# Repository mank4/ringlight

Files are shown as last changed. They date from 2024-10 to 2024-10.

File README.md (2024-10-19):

# Ringlight

ringlight is a LED ringlight for the Wild M3B stereo microscope. It it is mounted using the objective and does not stick out from the shape of the Wild M3B. ringlight requires 2 PCBs, one for the control and one aluminum core PCB (normal PCB should be also sufficient) for the LEDs. A spacer for mounting can be 3D printed.
The inner diameter of the LED PCB is chosen so that a photography polarization filter could be placed inside, but this is not tested. There are also mounting threads for a lens, intended to be 3D printed using clear resin with the option to mount a polarization filter foil onto the LED side. This is also not tested.

Feature:
- 24x Cree J Series 2835 high-CRI LEDs
- 10-step brightness control
- full circle, half circle and quarter circle modes with adjustable section size
- more configurations using SCPI pc-based control via USB

## RP2040 toolchain

Clone ringlight next to pico folder containing pico-examples, pico-sdk and picotool.

- Clone dependencies: `git submodule init` and `git submodule update`
- Create build folder in firmware and cd into. `cd fw && mkdir build && cd build`
- Then run `export PICO_SDK_PATH=../../../pico/pico-sdk` and `cmake ..`
- Then `make -j4`
- If compilation fails with USB descriptor length errors, do the following, cd into pico-sdk folder and `cd lib/tinyusb/` and then `git pull origin master`
- Then `../load.sh` with the RP2040 connected via USB. Press the button before pluggin in. (This is not needed when running the firmware. Make sure that picotool is build and you have set up the udev rules for the pico [udev rules](https://gist.github.com/alejoseb/c7a7b4c67f0cf665dadabb26a5a87597) and the ringlight:
```
/etc/udev/rules.d/99-ringlight.rules
SUBSYSTEMS=="usb", ACTION=="add", ATTRS{idVendor}=="16c0", ATTRS{idProduct}=="03e8",  MODE="0666", GROUP="usbtmc"
```

For details see the [Getting started](https://datasheets.raspberrypi.com/pico/getting-started-with-pico.pdf) guide.

## Resources

- Microcontroller
  - [RP2040](https://www.raspberrypi.com/documentation/microcontrollers/rp2040.html), [Pi pico](https://www.raspberrypi.com/products/raspberry-pi-pico/), RP2040 Minimal Kicad reference design
  - [SCPI specifications](https://www.ivifoundation.org/specifications/default.aspx), [SCPI-99 standard](https://www.ivifoundation.org/docs/scpi-99.pdf), [SCPI library](https://github.com/j123b567/scpi-parser)
  - [tinyusb for usbtmc](https://github.com/hathach/tinyusb), [example](https://github.com/markb139/pico_logic)

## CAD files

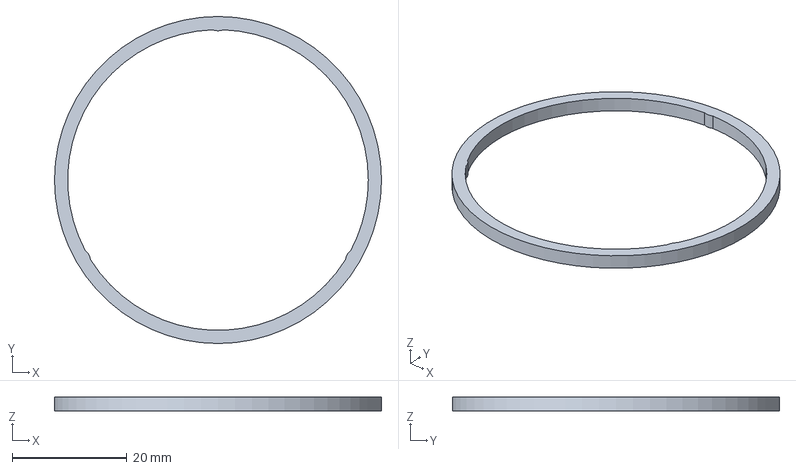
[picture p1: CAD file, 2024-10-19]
case/spacer1.FCStd
57.0 x 57.0 x 2.50 mm

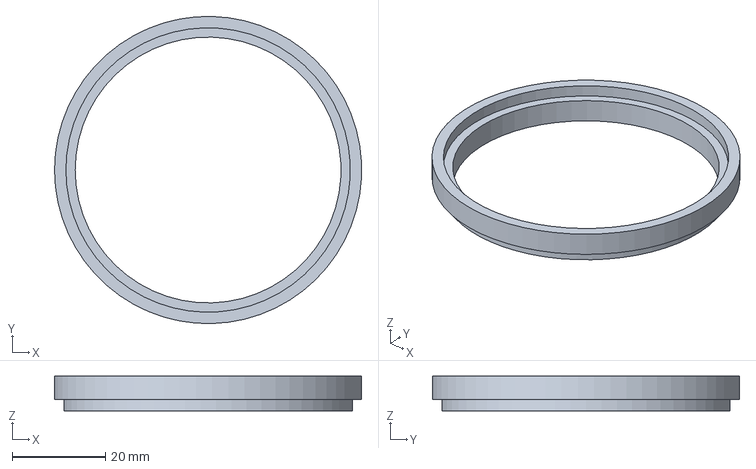
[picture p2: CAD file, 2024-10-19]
lens/filter.step
66.0 x 66.0 x 7.50 mm

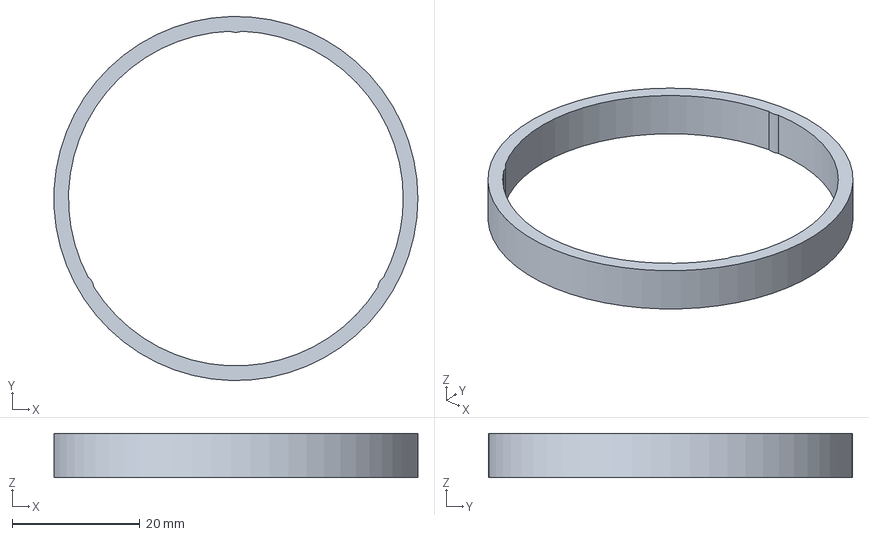
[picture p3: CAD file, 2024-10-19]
case/spacer2.FCStd
57.0 x 57.0 x 6.90 mm

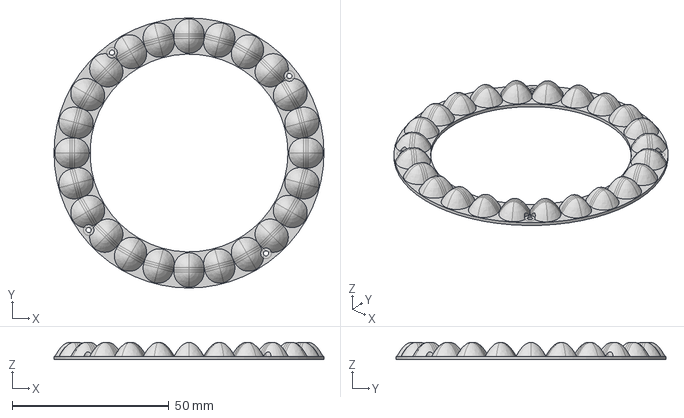
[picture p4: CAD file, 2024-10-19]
lens/lens.step
86.0 x 86.0 x 5.50 mm

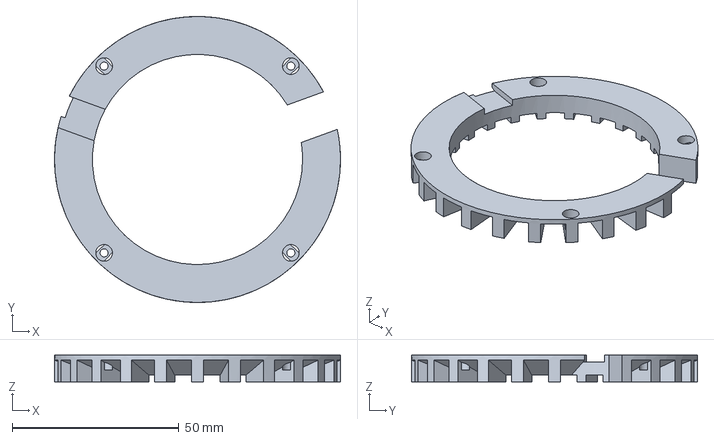
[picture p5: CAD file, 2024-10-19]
case/case.FCStd
85.7 x 85.7 x 8.00 mm

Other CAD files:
lens/lens.FCStd

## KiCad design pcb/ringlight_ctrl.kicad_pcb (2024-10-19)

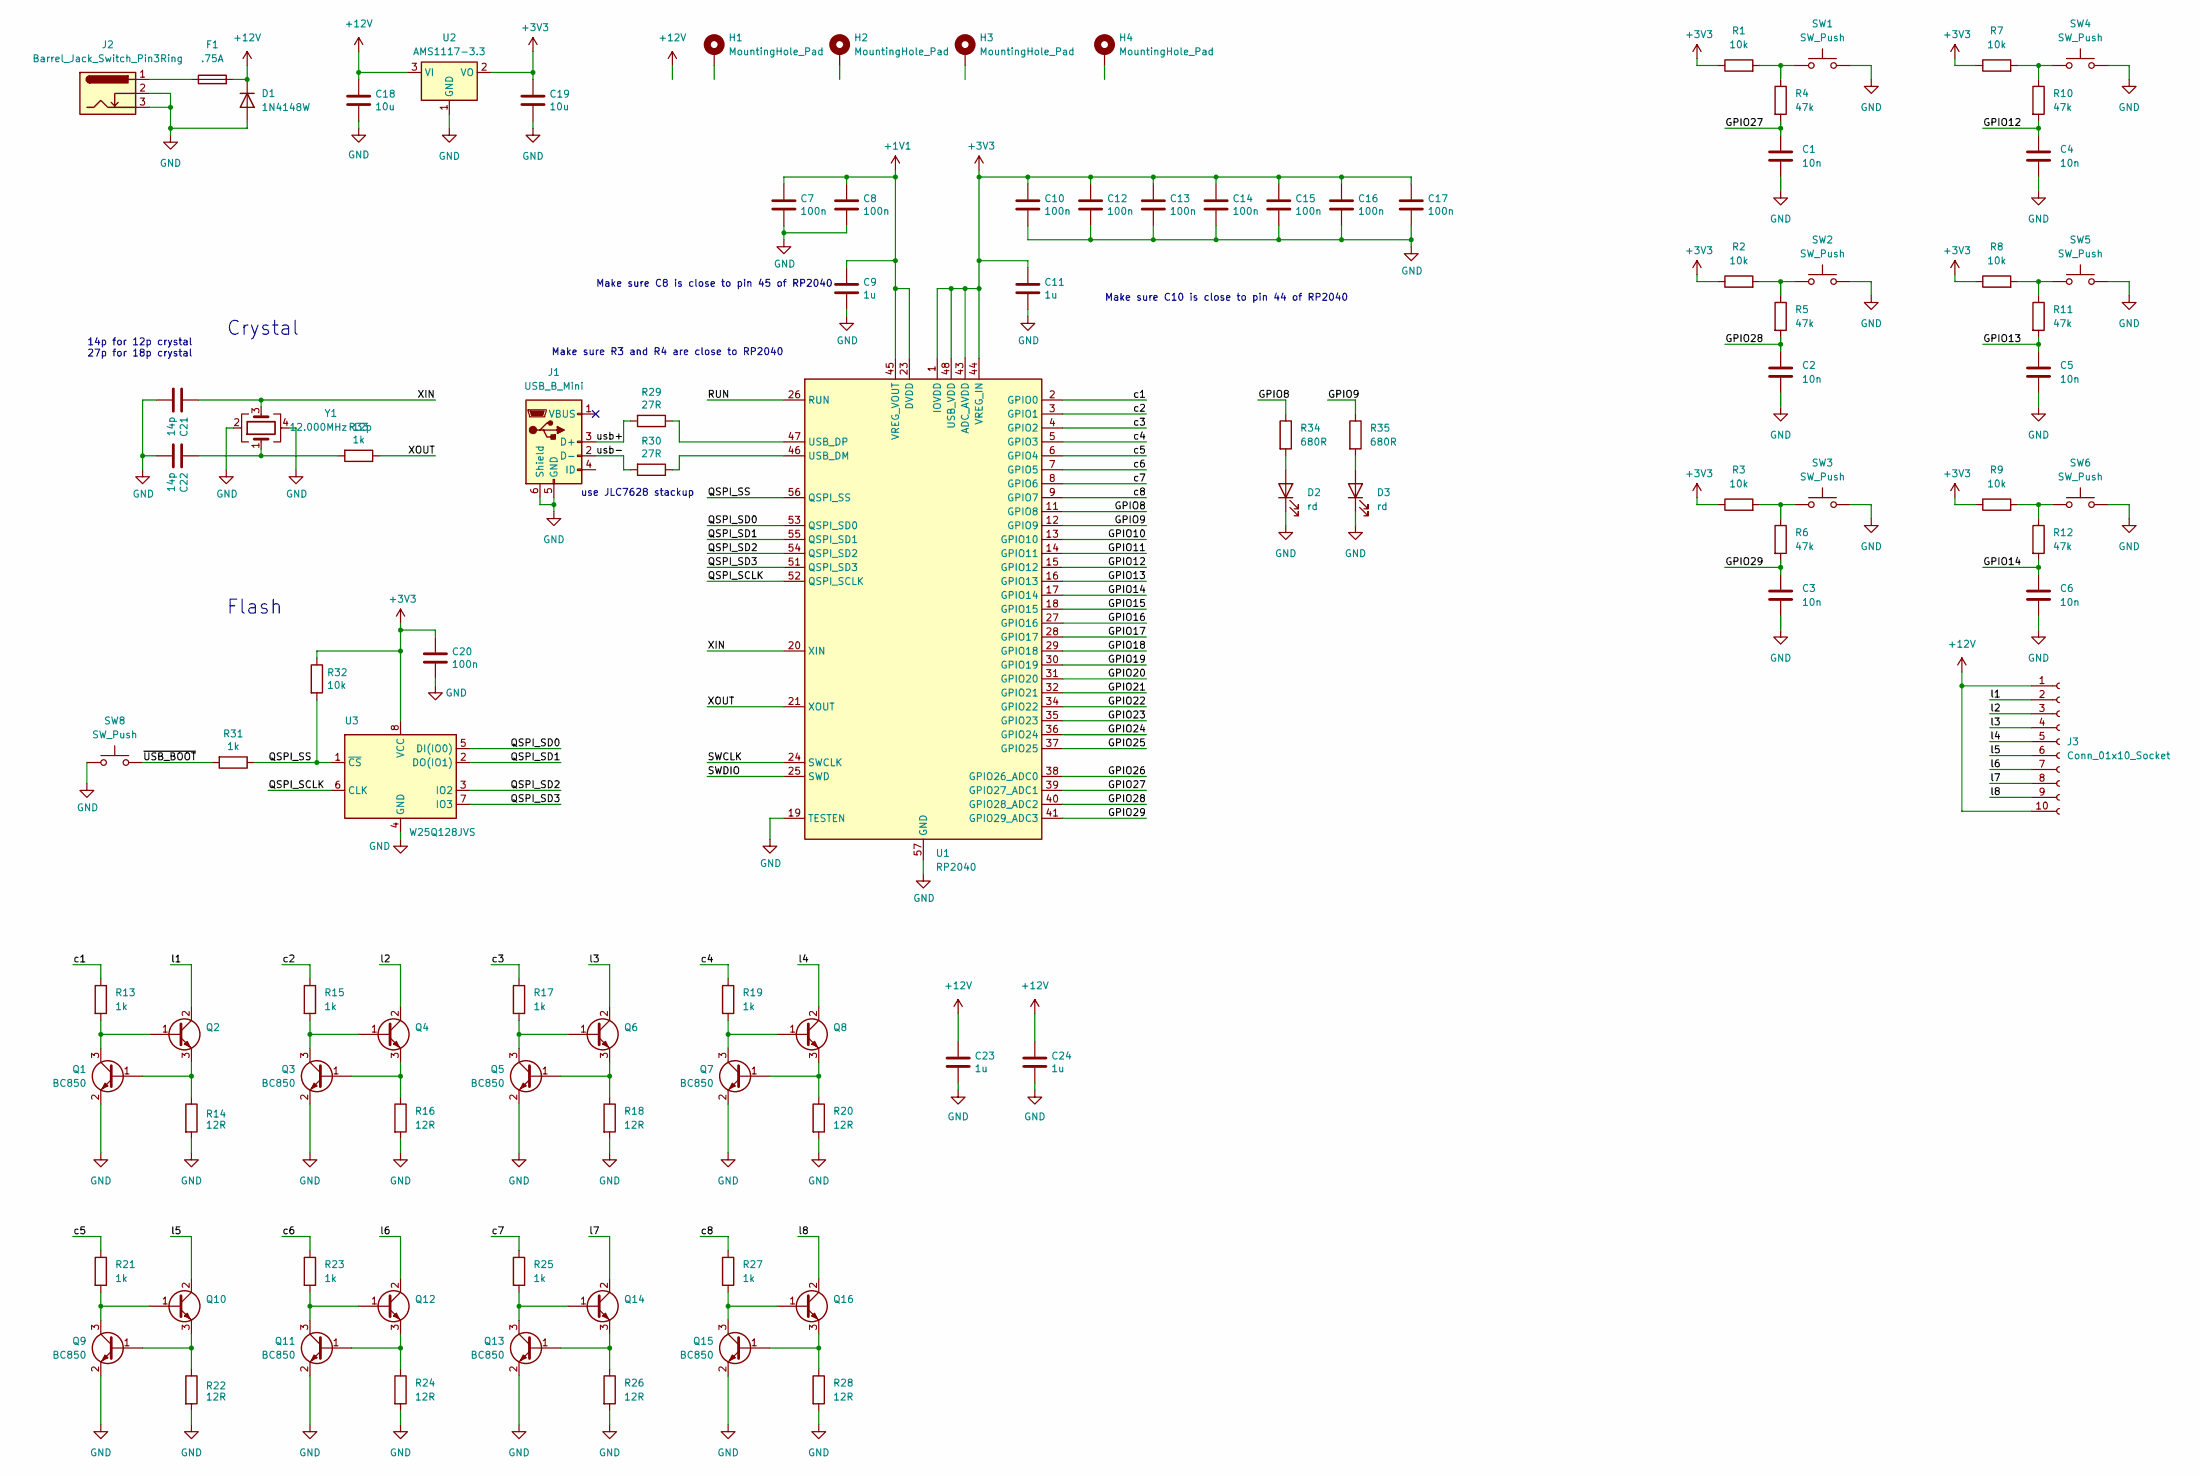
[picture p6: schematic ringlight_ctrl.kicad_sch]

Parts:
C1, C2, C3, C4, C5, C6: 10n; C_0805_2012Metric
C7, C8, C10, C12, C13, C14, C15, C16, C17, C20: 100n; C_0805_2012Metric
C9, C11, C23, C24: 1u; C_0805_2012Metric
C18, C19: 10u; C_0805_2012Metric
C21, C22: 14p; C_0805_2012Metric
D1: 1N4148W; D_SOD-123; Digikey 4878-1N4148WCT-ND
D2, D3: rd; LED_Kingbright_APA1606_1.6x0.6mm_Horizontal; Digikey 754-1054-1-ND
F1: .75A; Fuse_1206_3216Metric; Digikey 507-1805-1-ND
H1, H2, H3, H4: MountingHole_Pad; Mounting_Wuerth_WA-SMSI-M2_H8mm_9774080243; Digikey 732-7111-1-ND
J1: USB_B_Mini; USB_Mini-B_Wuerth_65100516121_Horizontal; Digikey 732-2109-1-ND
J2: Barrel_Jack_Switch_Pin3Ring; BarrelJack_CLIFF_FC681465S_SMT_Horizontal; Digikey 4654-FC681465S-ND
J3: Conn_01x10_Socket; conn_01x10
Q1, Q3, Q5, Q7, Q9, Q11, Q13, Q15: BC850; SOT-23; Digikey BC850BLT1GOSCT-ND
Q2, Q4, Q6, Q8, Q10, Q12, Q14, Q16: BCX56; SOT-89-3; Digikey 1727-2930-1-ND
R1, R2, R3, R7, R8, R9, R32: 10k; R_0805_2012Metric
R4, R5, R6, R10, R11, R12: 47k; R_0805_2012Metric
R13, R15, R17, R19, R21, R23, R25, R27, R31, R33: 1k; R_0805_2012Metric
R14, R16, R18, R20, R22, R24, R26, R28: 12R; R_0805_2012Metric
R29, R30: 27R; R_0805_2012Metric
R34, R35: 680R; R_0805_2012Metric
SW1, SW2, SW3, SW4, SW5, SW6: SW_Push; Panasonic_EVQPUL_EVQPUC; Digikey P10853SCT-ND
SW8: SW_Push; SW_Tactile_SPST_NO_Straight_CK_PTS636Sx25SMTRLFS; Digikey CKN12322-1-ND
U1: RP2040; QFN-56-1EP_7x7mm_P0.4mm_EP3.2x3.2mm; Digikey 2648-SC0914(13)CT-ND
U2: AMS1117-3.3; SOT-223-3_TabPin2
U3: W25Q128JVS; SOIC-8_5.23x5.23mm_P1.27mm; Digikey W25Q128JVSIQ-ND
Y1: 12.000MHz 12p; Crystal_SMD_Abracon_ABM3B-4Pin_5.0x3.2mm; Digikey 535-14827-1-ND

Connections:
+1V1: C7.1, C8.1, C9.1, U1.23 (DVDD), U1.45 (VREG_VOUT), U1.50 (DVDD)
+3V3: C10.1, C11.1, C12.1, C13.1, C14.1, C15.1, C16.1, C17.1, C19.1, C20.1, R1.1, R2.1, R3.1, R7.1, R8.1, R9.1, R32.1, U1.1 (IOVDD), U1.10 (IOVDD), U1.22 (IOVDD), U1.33 (IOVDD), U1.42 (IOVDD), U1.43 (ADC_AVDD), U1.44 (VREG_IN), U1.48 (USB_VDD), U1.49 (IOVDD), U2.2 (VO), U3.8 (VCC)
+12V: C18.1, C23.1, C24.1, D1.1 (K), F1.2, J3.1, J3.10, U2.3 (VI)
/GPIO8: R34.1, U1.11 (GPIO8)
/GPIO9: R35.1, U1.12 (GPIO9)
/GPIO10: U1.13 (GPIO10)
/GPIO11: U1.14 (GPIO11)
/GPIO12: C4.1, R10.2, U1.15 (GPIO12)
/GPIO13: C5.1, R11.2, U1.16 (GPIO13)
/GPIO14: C6.1, R12.2, U1.17 (GPIO14)
/GPIO15: U1.18 (GPIO15)
/GPIO16: U1.27 (GPIO16)
/GPIO17: U1.28 (GPIO17)
/GPIO18: U1.29 (GPIO18)
/GPIO19: U1.30 (GPIO19)
/GPIO20: U1.31 (GPIO20)
/GPIO21: U1.32 (GPIO21)
/GPIO22: U1.34 (GPIO22)
/GPIO23: U1.35 (GPIO23)
/GPIO24: U1.36 (GPIO24)
/GPIO25: U1.37 (GPIO25)
/GPIO26: U1.38 (GPIO26_ADC0)
/GPIO27: C1.1, R4.2, U1.39 (GPIO27_ADC1)
/GPIO28: C2.1, R5.2, U1.40 (GPIO28_ADC2)
/GPIO29: C3.1, R6.2, U1.41 (GPIO29_ADC3)
/QSPI_SCLK: U1.52 (QSPI_SCLK), U3.6 (CLK)
/QSPI_SD0: U1.53 (QSPI_SD0), U3.5 (DI(IO0))
/QSPI_SD1: U1.55 (QSPI_SD1), U3.2 (DO(IO1))
/QSPI_SD2: U1.54 (QSPI_SD2), U3.3 (IO2)
/QSPI_SD3: U1.51 (QSPI_SD3), U3.7 (IO3)
/QSPI_SS: R31.1, R32.2, U1.56 (QSPI_SS), U3.1 (~CS)
/RUN: U1.26 (RUN)
/SWCLK: U1.24 (SWCLK)
/SWDIO: U1.25 (SWD)
/XIN: C21.1, U1.20 (XIN), Y1.3
/XOUT: R33.1, U1.21 (XOUT)
/c1: R13.1, U1.2 (GPIO0)
/c2: R15.1, U1.3 (GPIO1)
/c3: R17.1, U1.4 (GPIO2)
/c4: R19.1, U1.5 (GPIO3)
/c5: R21.1, U1.6 (GPIO4)
/c6: R23.1, U1.7 (GPIO5)
/c7: R25.1, U1.8 (GPIO6)
/c8: R27.1, U1.9 (GPIO7)
/l1: J3.2, Q2.2 (C)
/l2: J3.3, Q4.2 (C)
/l3: J3.4, Q6.2 (C)
/l4: J3.5, Q8.2 (C)
/l5: J3.6, Q10.2 (C)
/l6: J3.7, Q12.2 (C)
/l7: J3.8, Q14.2 (C)
/l8: J3.9, Q16.2 (C)
/usb+: J1.3 (D+), R29.2
/usb-: J1.2 (D-), R30.2
/~USB_BOOT: R31.2, SW8.2
GND: C1.2, C2.2, C3.2, C4.2, C5.2, C6.2, C7.2, C8.2, C9.2, C10.2, C11.2, C12.2, C13.2, C14.2, C15.2, C16.2, C17.2, C18.2, C19.2, C20.2, C21.2, C22.2, C23.2, C24.2, D1.2 (A), D2.1 (K), D3.1 (K), J1.5 (GND), J1.6 (Shield), J2.2, J2.3, Q1.2 (E), Q3.2 (E), Q5.2 (E), Q7.2 (E), Q9.2 (E), Q11.2 (E), Q13.2 (E), Q15.2 (E), R14.2, R16.2, R18.2, R20.2, R22.2, R24.2, R26.2, R28.2, SW1.2, SW2.2, SW3.2, SW4.2, SW5.2, SW6.2, SW8.1, U1.19 (TESTEN), U1.57 (GND), U2.1 (GND), U3.4 (GND), Y1.2, Y1.4
unnamed: C22.1, R33.2, Y1.1
unnamed: D2.2 (A), R34.2
unnamed: D3.2 (A), R35.2
unnamed: F1.1, J2.1
unnamed: Q1.1 (B), Q2.3 (E), R14.1
unnamed: Q1.3 (C), Q2.1 (B), R13.2
unnamed: Q3.1 (B), Q4.3 (E), R16.1
unnamed: Q3.3 (C), Q4.1 (B), R15.2
unnamed: Q5.1 (B), Q6.3 (E), R18.1
unnamed: Q5.3 (C), Q6.1 (B), R17.2
unnamed: Q7.1 (B), Q8.3 (E), R20.1
unnamed: Q7.3 (C), Q8.1 (B), R19.2
unnamed: Q9.3 (C), Q10.1 (B), R21.2
unnamed: Q9.1 (B), Q10.3 (E), R22.1
unnamed: Q11.1 (B), Q12.3 (E), R24.1
unnamed: Q11.3 (C), Q12.1 (B), R23.2
unnamed: Q13.1 (B), Q14.3 (E), R26.1
unnamed: Q13.3 (C), Q14.1 (B), R25.2
unnamed: Q15.1 (B), Q16.3 (E), R28.1
unnamed: Q15.3 (C), Q16.1 (B), R27.2
unnamed: R1.2, R4.1, SW1.1
unnamed: R2.2, R5.1, SW2.1
unnamed: R3.2, R6.1, SW3.1
unnamed: R7.2, R10.1, SW4.1
unnamed: R8.2, R11.1, SW5.1
unnamed: R9.2, R12.1, SW6.1
unnamed: R30.1, U1.46 (USB_DM)
unnamed: R29.1, U1.47 (USB_DP)

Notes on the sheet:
Crystal
Make sure R3 and R4 are close to RP2040
14p for 12p crystal 27p for 18p crystal
Make sure C10 is close to pin 44 of RP2040
use JLC7628 stackup
Flash
Make sure C8 is close to pin 45 of RP2040

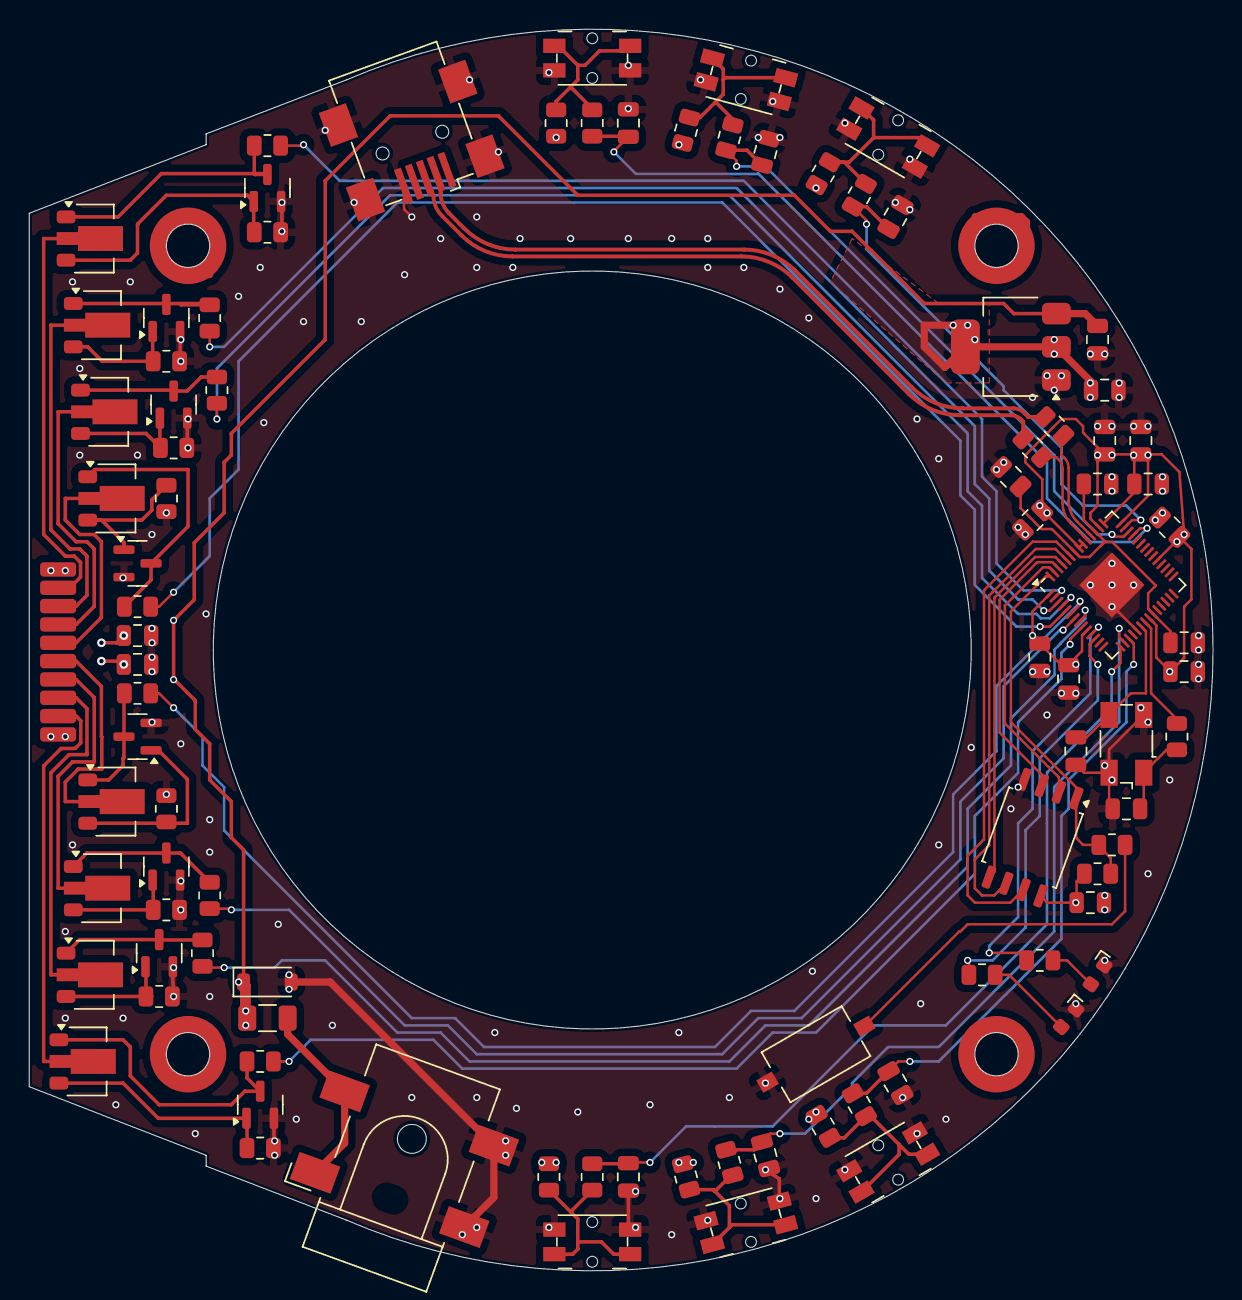
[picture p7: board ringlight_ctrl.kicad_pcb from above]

Board: 4 copper layers, 82.0 x 86.0 mm, 97 parts (0 on the bottom side), 67 nets.

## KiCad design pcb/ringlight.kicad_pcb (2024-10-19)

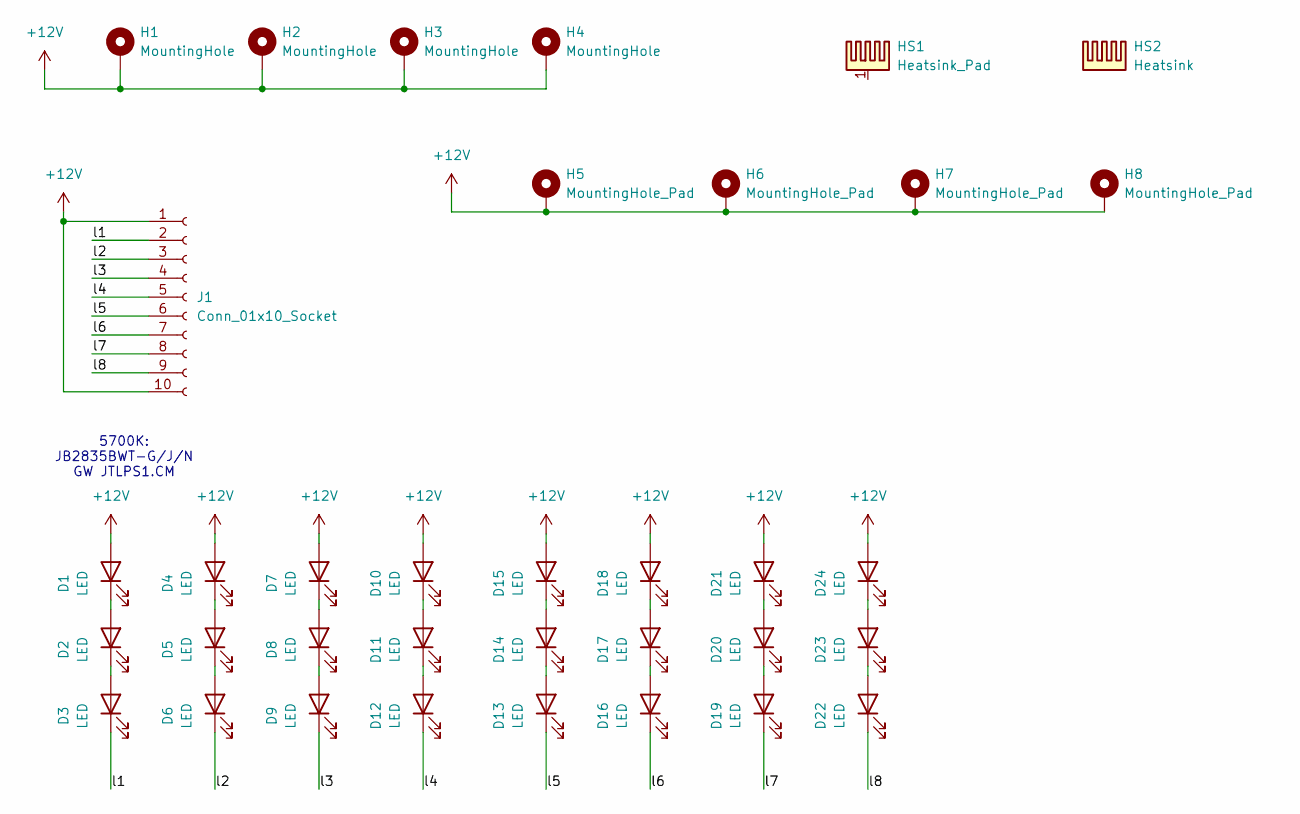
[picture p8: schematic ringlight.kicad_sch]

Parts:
D1, D2, D3, D4, D5, D6, D7, D8, D9, D10, D11, D12, D13, D14, D15, D16, D17, D18, D19, D20, D21, D22, D23, D24: LED; LED_PLCC_2835; Digikey 2138-JB2835BWT-G-U57EA0000-N000P001CT-ND
H1, H2, H3, H4: MountingHole; Mounting_Wuerth_WA-SMSI-M1.6_H1.5mm_9774015633; Digikey 732-13689-1-ND
H5, H6, H7, H8: MountingHole_Pad; MountingHole_2.2mm_M2_ISO14580_Pad
HS1: Heatsink_Pad; lens
HS2: Heatsink; filter
J1: Conn_01x10_Socket; conn_01x10

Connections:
+12V: D1.2 (A), D4.2 (A), D7.2 (A), D10.2 (A), D15.2 (A), D18.2 (A), D21.2 (A), D24.2 (A), H1.1, H2.1, H3.1, H4.1, H5.1, H6.1, H7.1, H8.1, J1.1, J1.10
/l1: D3.1 (K), J1.2
/l2: D6.1 (K), J1.3
/l3: D9.1 (K), J1.4
/l4: D12.1 (K), J1.5
/l5: D13.1 (K), J1.6
/l6: D16.1 (K), J1.7
/l7: D19.1 (K), J1.8
/l8: D22.1 (K), J1.9
unnamed: D1.1 (K), D2.2 (A)
unnamed: D2.1 (K), D3.2 (A)
unnamed: D4.1 (K), D5.2 (A)
unnamed: D5.1 (K), D6.2 (A)
unnamed: D7.1 (K), D8.2 (A)
unnamed: D8.1 (K), D9.2 (A)
unnamed: D10.1 (K), D11.2 (A)
unnamed: D11.1 (K), D12.2 (A)
unnamed: D13.2 (A), D14.1 (K)
unnamed: D14.2 (A), D15.1 (K)
unnamed: D16.2 (A), D17.1 (K)
unnamed: D17.2 (A), D18.1 (K)
unnamed: D19.2 (A), D20.1 (K)
unnamed: D20.2 (A), D21.1 (K)
unnamed: D22.2 (A), D23.1 (K)
unnamed: D23.2 (A), D24.1 (K)

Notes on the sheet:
5700K: JB2835BWT-G/J/N GW JTLPS1.CM

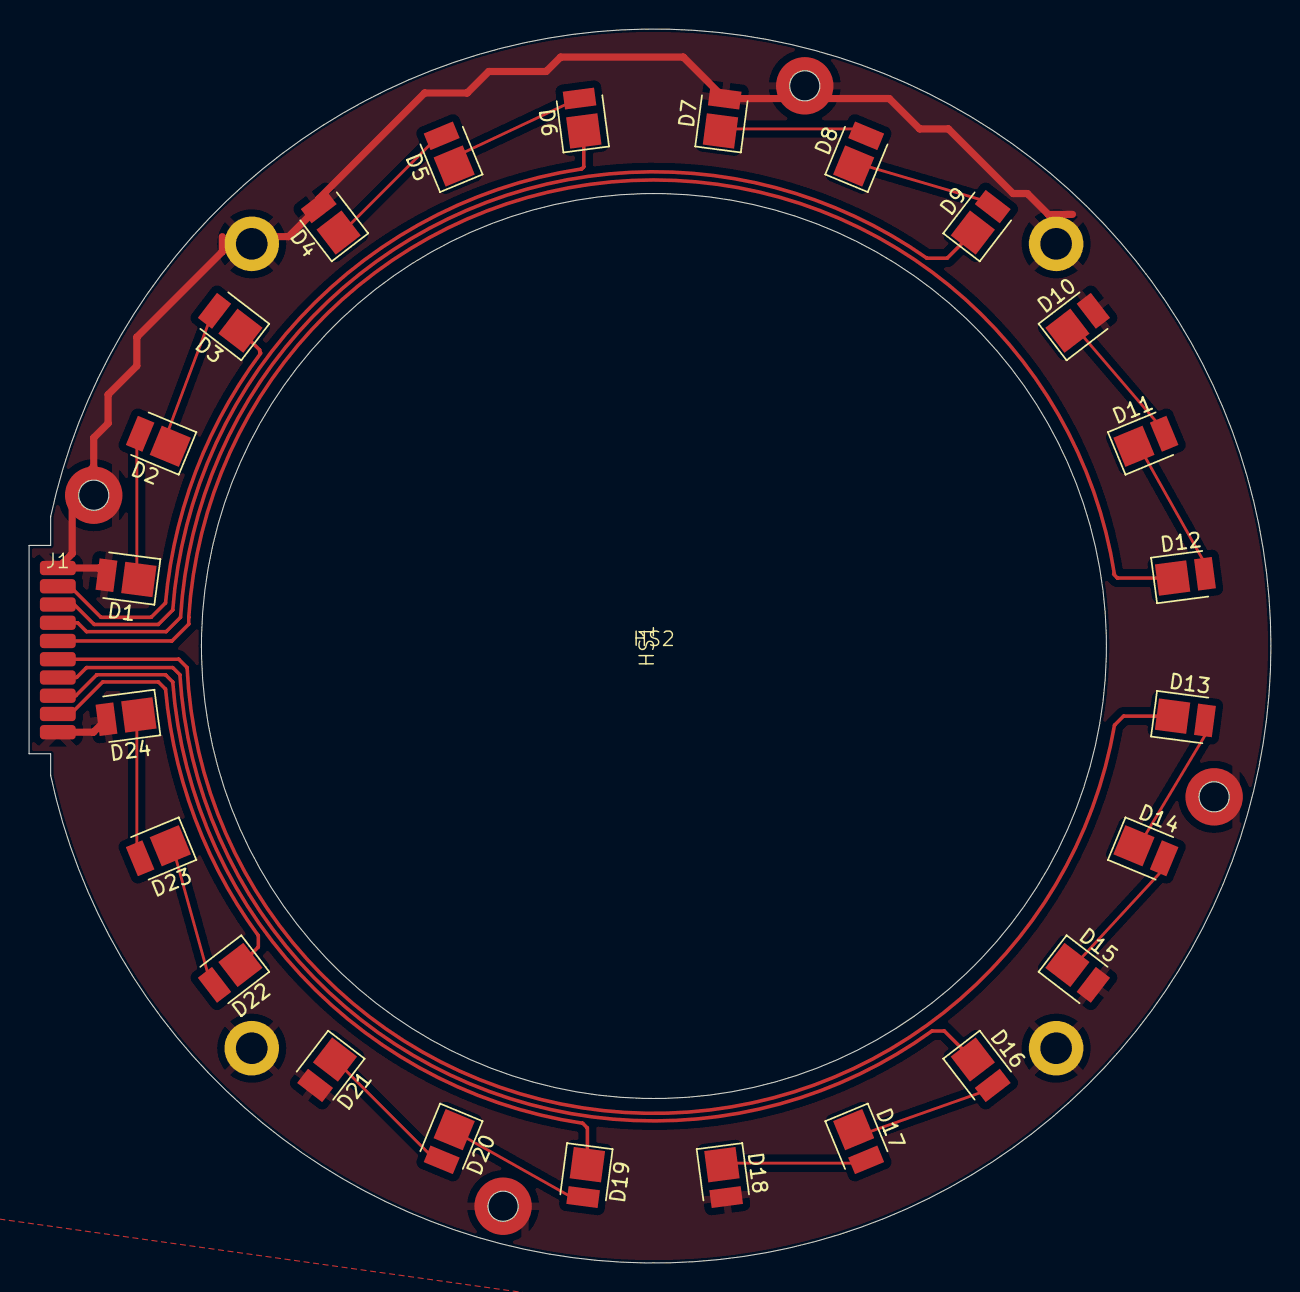
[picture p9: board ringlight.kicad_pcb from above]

Board: 2 copper layers, 86.5 x 85.9 mm, 35 parts (0 on the bottom side), 25 nets.

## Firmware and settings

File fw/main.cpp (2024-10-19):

#include <stdlib.h>
#include <stdio.h>

#include "pico/stdlib.h"
#include "pico/bootrom.h"
#include "hardware/pwm.h"

#include "scpi/scpi.h"
#include "usbtmc_app.h"

#define PIN_INDICATOR1 8
#define PIN_INDICATOR2 9

#define PIN_LED1 0
#define PIN_LED2 1
#define PIN_LED3 2
#define PIN_LED4 3
#define PIN_LED5 4
#define PIN_LED6 5
#define PIN_LED7 6
#define PIN_LED8 7

#define BTN_DLY 275
#define BTN_P 12
#define BTN_N 14
#define BTN_EN 13
#define BTN_SEC_NUM 28
#define BTN_SEC_SIZE 29
#define BTN_SEC_ORIENT 27

bool enable = true;
uint8_t brightness = 2; //steps from 0 to 9, human perceptions seems to be logarithmic
uint8_t section_num = 1; //number of sections
uint8_t section_size = 8; //size of sections
uint8_t section_orient = 0; //orientation of sections

void led_init()
{
    gpio_set_function(PIN_LED1, GPIO_FUNC_PWM);
    gpio_set_function(PIN_LED2, GPIO_FUNC_PWM);
    gpio_set_function(PIN_LED3, GPIO_FUNC_PWM);
    gpio_set_function(PIN_LED4, GPIO_FUNC_PWM);
    gpio_set_function(PIN_LED5, GPIO_FUNC_PWM);
    gpio_set_function(PIN_LED6, GPIO_FUNC_PWM);
    gpio_set_function(PIN_LED7, GPIO_FUNC_PWM);
    gpio_set_function(PIN_LED8, GPIO_FUNC_PWM);
    
    for(uint i = 0; i < 8; i++) {
        uint slice_num = pwm_gpio_to_slice_num(i);
        pwm_set_wrap(slice_num, 65535);
        pwm_set_gpio_level(i, 0);
        pwm_set_enabled(slice_num, true);
    }
    
    return;
}

void led_set()
{   
    //e^[1-10]/22026*65535
    //2.25^[1-10]/3325.25*65535
    const uint16_t leveltopwm[10] = {44,100,224,505,1136,2557,5753,12946,29127,65535};
    
    uint16_t pwmVal = leveltopwm[brightness];
    if(!enable) {
        pwmVal = 0;
    }
    
    uint16_t pwmVals[8] = {0,0,0,0,0,0,0,0};
    
    for(uint16_t i = 8+section_orient-section_size/2; i < 16+section_orient-section_size/2; i+=(8/section_num)) {
        for(uint16_t j = 0; j < section_size; j++) {
            pwmVals[(i+j)%8] = pwmVal;
        }
    }

    for(uint16_t i = 0; i < 8; i++) {
        pwm_set_gpio_level(i, pwmVals[i]);
    }
    
    return;
}

static scpi_result_t pi_led_enable_set(scpi_t* context) {
    bool value = false;
    
    if(!SCPI_ParamBool(context, &value, true)) {
        SCPI_ErrorPush(context, SCPI_ERROR_ILLEGAL_PARAMETER_VALUE);
    } else {
        enable = value;
        led_set();
    }
    
    return SCPI_RES_OK;
}

static scpi_result_t pi_led_brightness_set(scpi_t* context) {
    uint32_t value = 255;
    SCPI_ParamUInt32(context, &value, true);
    
    if(value < 0 || value > 9) {
        SCPI_ErrorPush(context, SCPI_ERROR_ILLEGAL_PARAMETER_VALUE);
    } else {
        brightness = value;
        led_set();
    }
    
    return SCPI_RES_OK;
}

static scpi_result_t pi_led_section_num_set(scpi_t* context) {
    uint32_t value = 255;
    SCPI_ParamUInt32(context, &value, true);
    
    if(value != 1 && value != 2 && value != 4) {
        SCPI_ErrorPush(context, SCPI_ERROR_ILLEGAL_PARAMETER_VALUE);
    } else {
        section_num = value;
        led_set();
    }
    
    return SCPI_RES_OK;
}

static scpi_result_t pi_led_section_size_set(scpi_t* context) {
    uint32_t value = 255;
    SCPI_ParamUInt32(context, &value, true);
    
    if(value < 1 || value > 8) {
        SCPI_ErrorPush(context, SCPI_ERROR_ILLEGAL_PARAMETER_VALUE);
    } else {
        section_size = value;
        led_set();
    }
    
    return SCPI_RES_OK;
}

static scpi_result_t pi_led_section_orient_set(scpi_t* context) {
    uint32_t value = 255;
    SCPI_ParamUInt32(context, &value, true);
    
    if(value < 0 || value > 7) {
        SCPI_ErrorPush(context, SCPI_ERROR_ILLEGAL_PARAMETER_VALUE);
    } else {
        section_orient = value;
        led_set();
    }
    
    return SCPI_RES_OK;
}

static scpi_result_t pi_led_individual_set(scpi_t* context) {
    uint32_t value = 255;
    
    SCPI_ParamUInt32(context, &value, true);
    
    if(value < 0 || value > 65535) {
        SCPI_ErrorPush(context, SCPI_ERROR_ILLEGAL_PARAMETER_VALUE);
    } else {
        pwm_set_gpio_level(2, value);
    }
    
    return SCPI_RES_OK;
}

#define SCPI_ERROR_QUEUE_SIZE 17
scpi_error_t scpi_error_queue_data[SCPI_ERROR_QUEUE_SIZE];

//#define SCPI_INPUT_BUFFER_LENGTH 256
//static char scpi_input_buffer[SCPI_INPUT_BUFFER_LENGTH];

bool scpi_doIndicatorPulse = 0;
absolute_time_t scpi_doIndicatorPulseUntil;

//###########################################
// SCPI callbacks
//###########################################

static scpi_result_t pi_echo(scpi_t* context) {
    char retVal[500] = "hm";
    size_t text_len = 3;
    
    if(!SCPI_ParamCopyText(context, retVal, sizeof(retVal), &text_len, true)) {
        
    }
    
    SCPI_ResultCharacters(context, retVal, text_len);
    
    return SCPI_RES_OK;
}

static scpi_result_t pi_bootsel(scpi_t* context) {
    reset_usb_boot(PIN_INDICATOR1, 0);
    
    return SCPI_RES_OK;
}

//###########################################
// SCPI callback definition
//###########################################

scpi_command_t scpi_commands[] = {
    /* IEEE Mandated Commands (SCPI std V1999.0 4.1.1) */
    {"*CLS", SCPI_CoreCls, 0},
    {"*ESE", SCPI_CoreEse, 0},
    {"*ESE?", SCPI_CoreEseQ, 0},
    {"*ESR?", SCPI_CoreEsrQ, 0},
    {"*IDN?", SCPI_CoreIdnQ, 0},
    {"*OPC", SCPI_CoreOpc, 0},
    {"*OPC?", SCPI_CoreOpcQ, 0},
    {"*RST", SCPI_CoreRst, 0},
    {"*SRE", SCPI_CoreSre, 0},
    {"*SRE?", SCPI_CoreSreQ, 0},
    {"*STB?", SCPI_CoreStbQ, 0},
    {"*TST?", SCPI_CoreTstQ, 0},
    {"*WAI", SCPI_CoreWai, 0},
    
    /* Required SCPI commands (SCPI std V1999.0 4.2.1) */
    {"SYSTem:ERRor[:NEXT]?", SCPI_SystemErrorNextQ, 0},
    {"SYSTem:ERRor:COUNt?", SCPI_SystemErrorCountQ, 0},
    {"SYSTem:VERSion?", SCPI_SystemVersionQ, 0},

    //{"STATus:OPERation?", scpi_stub_callback, 0},
    //{"STATus:OPERation:EVENt?", scpi_stub_callback, 0},
    //{"STATus:OPERation:CONDition?", scpi_stub_callback, 0},
    //{"STATus:OPERation:ENABle", scpi_stub_callback, 0},
    //{"STATus:OPERation:ENABle?", scpi_stub_callback, 0},

    {"STATus:QUEStionable[:EVENt]?", SCPI_StatusQuestionableEventQ, 0},
    //{"STATus:QUEStionable:CONDition?", scpi_stub_callback, 0},
    {"STATus:QUEStionable:ENABle", SCPI_StatusQuestionableEnable, 0},
    {"STATus:QUEStionable:ENABle?", SCPI_StatusQuestionableEnableQ, 0},

    {"STATus:PRESet", SCPI_StatusPreset, 0},
    
    /* probeInterface */
    { .pattern = "ECHO", .callback = pi_echo,},
    { .pattern = "BOOTSEL", .callback = pi_bootsel,},
    
    { .pattern = "LED:INDIvidual", .callback = pi_led_individual_set,},
    { .pattern = "LED:ENable", .callback = pi_led_enable_set,},
    { .pattern = "LED:BRIGHTness", .callback = pi_led_brightness_set,},
    { .pattern = "LED:SECtion:NUMber", .callback = pi_led_section_num_set,},
    { .pattern = "LED:SECtion:SIZE", .callback = pi_led_section_size_set,},
    { .pattern = "LED:SECtion:ORIENTation", .callback = pi_led_section_orient_set,},
    
	SCPI_CMD_LIST_END
};

scpi_t scpi_context;

size_t scpi_write(scpi_t * context, const char * data, size_t len) {
    (void) context;
    usbtmc_app_response(data, len, false);
    return len;
}

scpi_result_t scpi_flush(scpi_t* context) {
    SCPI_RegSetBits(context, SCPI_REG_STB, STB_MAV);
    usbtmc_app_response(NULL, 0, true);
    return SCPI_RES_OK;
}

scpi_interface_t scpi_interface = {
    /*.error = */ NULL,
    /*.write = */ scpi_write,
    /*.control = */ NULL,
    /*.flush = */ scpi_flush,
    /*.reset = */ NULL,
};

//###########################################
// USB callbacks
//###########################################

void usbtmc_app_query_cb(char* data, size_t len)
{
    //use usb internal buffer and SCPI_Parse
    //use scpi library for ieee488.2
    SCPI_Parse(&scpi_context, data, len);
    return;
}

uint8_t usbtmc_app_get_stb_cb(void)
{
    uint8_t status = SCPI_RegGet(&scpi_context, SCPI_REG_STB);
    SCPI_RegClearBits(&scpi_context, SCPI_REG_STB, STB_SRQ);
    return status;
}

void usbtmc_app_clear_stb_cb(void)
{
    SCPI_RegClearBits(&scpi_context, SCPI_REG_STB, 0xff);
}

void usbtmc_app_clear_mav_cb(void)
{
    SCPI_RegClearBits(&scpi_context, SCPI_REG_STB, STB_MAV);
}

void usbtmc_app_set_srq_cb(void)
{
    scpi_context.registers[SCPI_REG_STB] |= STB_SRQ;
    //SCPI_RegSetBits(&scpi_context, SCPI_REG_STB, STB_SRQ);
}

void usbtmc_app_clear_srq_cb(void)
{
    scpi_context.registers[SCPI_REG_STB] &= ~STB_SRQ;
    //SCPI_RegClearBits(&scpi_context, SCPI_REG_STB, STB_SRQ);
}

//indicator light is required by IEEE 488.2
void usbtmc_app_indicator_cb(void)
{
    gpio_put(PIN_INDICATOR1, 1);
    scpi_doIndicatorPulse = true;
    scpi_doIndicatorPulseUntil = make_timeout_time_ms(750);
}

//###########################################
// main application
//###########################################

int main() {
    stdio_init_all();
    
    //led ring
    led_init();
    led_set();
    
    gpio_init(PIN_INDICATOR1);
    gpio_set_dir(PIN_INDICATOR1, GPIO_OUT);
    gpio_put(PIN_INDICATOR1, 1);
    //printf("RP2040 booting...\n");
    sleep_ms(1000);
    gpio_put(PIN_INDICATOR1, 0);
    
    gpio_init(PIN_INDICATOR2);
    gpio_set_dir(PIN_INDICATOR2, GPIO_OUT);
    gpio_put(PIN_INDICATOR2, 0);
    
    gpio_init(BTN_P);
    gpio_init(BTN_N);
    gpio_init(BTN_EN);
    gpio_init(BTN_SEC_NUM);
    gpio_init(BTN_SEC_SIZE);
    gpio_init(BTN_SEC_ORIENT);
    
    gpio_set_dir(BTN_P, GPIO_IN);
    gpio_set_pulls(BTN_P, false, false);
    gpio_set_dir(BTN_N, GPIO_IN);
    gpio_set_pulls(BTN_N, false, false);
    gpio_set_dir(BTN_EN, GPIO_IN);
    gpio_set_pulls(BTN_EN, false, false);
    gpio_set_dir(BTN_SEC_NUM, GPIO_IN);
    gpio_set_pulls(BTN_SEC_NUM, false, false);
    gpio_set_dir(BTN_SEC_SIZE, GPIO_IN);
    gpio_set_pulls(BTN_SEC_SIZE, false, false);
    gpio_set_dir(BTN_SEC_ORIENT, GPIO_IN);
    gpio_set_pulls(BTN_SEC_ORIENT, false, false);
    
    SCPI_Init(&scpi_context,
              scpi_commands,
              &scpi_interface,
              scpi_units_def,
              "mank electronics", "ringlight", "v0.1", "dev",
              NULL, 0, //scpi_input_buffer, SCPI_INPUT_BUFFER_LENGTH,
              scpi_error_queue_data, SCPI_ERROR_QUEUE_SIZE
    );
    
    usbtmc_app_init();
    
    while (true) {
        //this is not a good coding style but should be ok for this simple project
        if(!gpio_get(BTN_EN)) {
            gpio_put(PIN_INDICATOR2, enable);
            enable = !enable;
            led_set();
            sleep_ms(BTN_DLY);
        }
        if(enable && !gpio_get(BTN_P)) {
            if(brightness < 9) {
                brightness++;
                led_set();
            } else {
                gpio_put(PIN_INDICATOR2, 1);
            }
            sleep_ms(BTN_DLY);
            gpio_put(PIN_INDICATOR2, 0);
        }
        if(enable && !gpio_get(BTN_N)) {
            if(brightness > 0) {
                brightness--;
                led_set();
            } else {
                gpio_put(PIN_INDICATOR2, 1);
            }
            sleep_ms(BTN_DLY);
            gpio_put(PIN_INDICATOR2, 0);
        }
        if(enable && !gpio_get(BTN_SEC_NUM)) {
            //switch between single, double and full
            if(section_num == 1 && section_size == 8) {
                section_num = 1;
                section_size = 2;
            } else if(section_num == 1 && section_size < 8) {
                section_num = 2;
                section_size = 2;
            } else {
                section_num = 1;
                section_size = 8;
            }
            led_set();
            sleep_ms(BTN_DLY);
        }
        if(enable && !gpio_get(BTN_SEC_SIZE)) {
            //switch size of segments
            if(section_num == 1 && section_size < 8) {
                section_size++;
                if(section_size > 6)
                    section_size = 1;
            } else if(section_num == 2) {
                section_size++;
                if(section_size > 2)
                    section_size = 1;
            }
            led_set();
            sleep_ms(BTN_DLY);
        }
        if(enable && !gpio_get(BTN_SEC_ORIENT)) {
            section_orient++;
            if(section_orient > 7)
                section_orient = 0;
            led_set();
            sleep_ms(BTN_DLY);
        }
        
        if(scpi_doIndicatorPulse && get_absolute_time() > scpi_doIndicatorPulseUntil) {
            scpi_doIndicatorPulse = false;
            gpio_put(PIN_INDICATOR1, 0);
        }
        
        usbtmc_app_task_iter();
    }
}

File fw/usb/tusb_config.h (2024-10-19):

/*
 * tusb_config.h
 *
 *  Created on: Sep 5, 2019
 *      Author: nconrad
 */

#ifndef TUSB_CONFIG_H_
#define TUSB_CONFIG_H_

#ifdef __cplusplus
 extern "C" {
#endif

//--------------------------------------------------------------------+
// Board Specific Configuration
//--------------------------------------------------------------------+

// RHPort number used for device can be defined by board.mk, default to port 0
#ifndef BOARD_TUD_RHPORT
#define BOARD_TUD_RHPORT      0
#endif

// RHPort max operational speed can defined by board.mk
#ifndef BOARD_TUD_MAX_SPEED
#define BOARD_TUD_MAX_SPEED   OPT_MODE_DEFAULT_SPEED
#endif

//--------------------------------------------------------------------
// Common Configuration
//--------------------------------------------------------------------

// defined by compiler flags for flexibility
#ifndef CFG_TUSB_MCU
#error CFG_TUSB_MCU must be defined
#endif

#ifndef CFG_TUSB_OS
#define CFG_TUSB_OS           OPT_OS_NONE
#endif

#ifndef CFG_TUSB_DEBUG
#define CFG_TUSB_DEBUG        0
#endif

// Enable Device stack
#define CFG_TUD_ENABLED       1

// Default is max speed that hardware controller could support with on-chip PHY
#define CFG_TUD_MAX_SPEED     BOARD_TUD_MAX_SPEED

/* USB DMA on some MCUs can only access a specific SRAM region with restriction on alignment.
 * Tinyusb use follows macros to declare transferring memory so that they can be put
 * into those specific section.
 * e.g
 * - CFG_TUSB_MEM SECTION : __attribute__ (( section(".usb_ram") ))
 * - CFG_TUSB_MEM_ALIGN   : __attribute__ ((aligned(4)))
 */
#ifndef CFG_TUSB_MEM_SECTION
#define CFG_TUSB_MEM_SECTION
#endif

#ifndef CFG_TUSB_MEM_ALIGN
#define CFG_TUSB_MEM_ALIGN        __attribute__ ((aligned(4)))
#endif

//--------------------------------------------------------------------
// DEVICE CONFIGURATION
//--------------------------------------------------------------------

#ifndef CFG_TUD_ENDPOINT0_SIZE
#define CFG_TUD_ENDPOINT0_SIZE    64
#endif

//------------- CLASS -------------//

#define CFG_TUD_USBTMC                1
#define CFG_TUD_USBTMC_ENABLE_INT_EP  1
#define CFG_TUD_USBTMC_ENABLE_488     1

#ifdef __cplusplus
 }
#endif

#endif /* TUSB_CONFIG_H_ */ 
